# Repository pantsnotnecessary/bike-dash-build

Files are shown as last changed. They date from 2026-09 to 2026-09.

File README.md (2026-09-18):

# bike-dash-build

Hardware + software build notes for the **permanent** electric-motorcycle dash.
This repo is the "how to build it" companion to two existing repos:

| Repo | What it holds |
|---|---|
| [pantsnotnecessary/bike-dash](https://github.com/pantsnotnecessary/bike-dash) (private) | The dash firmware (ESPHome/LVGL): GPS speed, BMS status, media strip, SD ride log |
| [pantsnotnecessary/ant-bms-epaper-gauge](https://github.com/pantsnotnecessary/ant-bms-epaper-gauge) (public) | The original e-paper SOC gauge; the ANT-BMS BLE logic came from here |

## The decision (2026-09-18)

Cost is not a factor. Performance and start-up time are.

| Question | Answer |
|---|---|
| Compute | **ESP32-P4 + ESP32-C6** under ESPHome. About 3 s from key-on to a usable screen. Everything already written for bike-dash carries over. |
| Why not a Pi / Linux board | 15-30 s boot. Rejected. |
| Why not STM32H7 | Under 1 s boot but no BLE and nothing carries over. Rejected. |
| Why not the Waveshare ESP32-P4-7B we started on | Its panel is **350 nits, 0-60 C**. Every ESP32-P4 all-in-one board on the market (Waveshare, Guition, Elecrow) is an indoor panel. A bike dash in direct sun needs about 1000 nits. |
| Screen | **Riverdi RVT70HSMNWC00-B**: 7" 1024x600 IPS, **850 cd/m2**, optically bonded PCAP touch, anti-glare, **-20 to 70 C**, glove and wet-screen touch. Controller EK79007 (same family as Espressif's own dev panel), runs 2-lane. |
| Board | **Waveshare ESP32-P4-NANO** (P4 + onboard C6, 32 MB PSRAM, 16 MB flash, microSD, 22-pin 2-lane DSI). |
| Glue | Two FPC breakouts for the bench, a PT4115 constant-current driver for the 9.6 V / 270 mA backlight, a Pololu 5 V buck off the bike's 12 V. A small carrier PCB replaces the breakouts for the on-bike install. |

## Bench wiring at a glance

Bench wiring diagram

Full pin-by-pin steps, checks and troubleshooting: [docs/wiring.md](docs/wiring.md).

## Where things are

| File | Contents |
|---|---|
| [docs/bom.md](docs/bom.md) | Every part, price, link, and order status |
| [docs/wiring.md](docs/wiring.md) | **Pin-for-pin wiring guide.** Start here when the parts arrive. |
| [docs/hardware.md](docs/hardware.md) | Pinouts, panel electrical limits, timings, gotchas (the reference behind the wiring guide) |
| [docs/software.md](docs/software.md) | ESPHome bring-up plan, versions, stages |
| [esphome/bike-dash-p4nano.yaml](esphome/bike-dash-p4nano.yaml) | Starting config: P4-NANO + Riverdi panel as a `mipi_dsi` CUSTOM model |
| [docs/build-log.md](docs/build-log.md) | Dated log of what was done and what was learned |
| [enclosure/](enclosure/README.md) | OpenSCAD model, STLs and previews of the printed housing (bezel, retainer, shell, GPS cap) |

## Enclosure at a glance

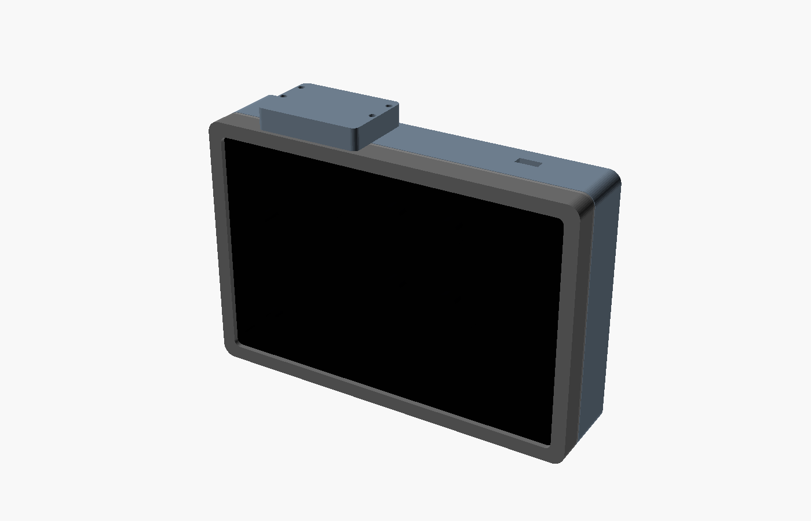
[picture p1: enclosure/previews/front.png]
Enclosure mockup


Four printed parts, PETG/ASA, M3 inserts. Details, hardware list and the VERIFY table: [enclosure/README.md](enclosure/README.md).

## Status

- 2026-09-18: research done, all core parts ordered (Amazon plus the Riverdi panel from DigiKey). Nothing built yet.
- 2026-09-18: enclosure mockup modelled in OpenSCAD, STLs exported. Several dimensions still need calipers on the real parts (see enclosure/README.md).

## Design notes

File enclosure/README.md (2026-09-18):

# Enclosure

Parametric OpenSCAD model of the dash housing: [bike-dash-enclosure.scad](bike-dash-enclosure.scad).
Four printed parts, all plastic so the BLE and GPS antennas work from inside.

Front

| View | Image |
|---|---|
| Exploded (bezel, retainer, shell, GPS cap) | [previews/exploded.png](previews/exploded.png) |
| Shell inside, boards as coloured blocks | [previews/shell-inside.png](previews/shell-inside.png) |
| Back, AMPS pattern and 7 assembly screws | [previews/back.png](previews/back.png) |
| Bezel from behind, insert holes and tail relief | [previews/bezel-back.png](previews/bezel-back.png) |
| GPS cap from inside | [previews/gpscap-inside.png](previews/gpscap-inside.png) |

## Parts

| Part | STL | Print orientation | What it does |
|---|---|---|---|
| Bezel | [stl/bezel.stl](stl/bezel.stl) | face down | Front frame. 4 mm lip over the glass edge on a foam gasket, glass pocket, then a TFT pocket open to the back. 7 x M3 heat-set inserts from the back. |
| Retainer | [stl/retainer.stl](stl/retainer.stl) | flat | 2 mm plate clamped between bezel and shell. Its raised frame enters the TFT pocket and presses the TFT back edge through 1 mm foam, so the panel cannot walk backwards under vibration. Slot in the bottom bar for the FPC tail. |
| Shell | [stl/shell.stl](stl/shell.stl) | back down | Rear box, 24 mm cavity. Standoffs for the P4-NANO (M2.5 self-tap) and Pololu, adhesive pads for the two FPC breakouts and the PT4115, PG7 gland in the bottom wall, USB-C slot in the top wall for bench flashing, AMPS 30 x 38 bosses with M4 inserts on the back, thick pad under the top wall for the GPS cap screws. |
| GPS cap | [stl/gpscap.stl](stl/gpscap.stl) | open side up | Cup on the top edge. The SparkFun NEO-M9N lies flat against the 1.5 mm roof, chip antenna to the sky. 4 x M3 button heads through the roof into inserts in the shell. |

Overall size 185.6 x 124.6 x 41.7 mm, GPS cap adds 10.6 mm on the top edge.

## Hardware to fit it together

| Item | Qty | Where |
|---|---|---|
| M3 heat-set insert, 4.0 mm OD x 5.7 mm | 11 | 7 in the bezel, 4 in the shell top wall (GPS cap) |
| M3 x 35 socket cap screw | 7 | shell back, through the bosses, into the bezel |
| M3 x 16 button head | 4 | GPS cap roof into the shell |
| M3 x 6 self-tapping (or M3 x 6 into 2.5 mm pilot) | 4 | GPS board to the cap standoffs |
| M2.5 x 8 self-tapping | 4 | P4-NANO to its standoffs |
| M2 x 6 self-tapping | 2 | Pololu buck |
| M4 heat-set insert, 5.6 mm OD x 8 mm | 4 | AMPS bosses on the back |
| PG7 cable gland | 1 | bottom wall, 12 V feed |
| Foam tape 1 mm, 5 mm wide | 1 m | gasket under the bezel lip; strip on the retainer frame |
| Double-sided foam tape | some | PT4115 and both FPC breakouts on their pads |

## Print settings

PETG or ASA (the dash sits in the sun; PLA will sag). 0.2 mm layers, 4 walls, 30 % infill, no supports needed in the orientations above. The bezel face is the visible surface, so use a textured or smooth PEI sheet. Print the retainer first: it is a 2 minute test of the screw pattern against the bezel.

## Regenerate

```
cd enclosure
for p in bezel retainer shell gpscap; do openscad -o stl/$p.stl -D "part=\"$p\"" bike-dash-enclosure.scad; done
openscad -o previews/front.png --imgsize=1400,900 --viewall --autocenter --projection=p --colorscheme=Tomorrow --camera=300,-500,300,0,0,0 -D 'part="assembly"' bike-dash-enclosure.scad
```

Other `part` values: `exploded`, `shell_inside`, `gpscap_inside`, `placeholders`.

## VERIFY before the final print

Every number tagged `VERIFY` in the .scad came from a drawing or listing, not from the part in hand.

| Dimension | Value used | Source | Check |
|---|---|---|---|
| Glass outline and thickness | 179.96 x 119.0 x 1.1 mm | Riverdi listing for the -B touch part | Calipers on the panel; the -B datasheet was not downloadable (404 on every revision tried) |
| TFT offset inside the glass | centred | assumption | The tail side is usually wider. Measure and set `tft_off` |
| Tail width and position | 30 mm, centred on the bottom edge | assumption | Measure; set `tail_w`, `tail_x`. The retainer slot and bezel relief follow |
| P4-NANO mounting holes | 45.10 x 45.09 mm, 2.7 mm | Waveshare dimension drawing | Hole diameter is a guess from the "R2.00" callout |
| RJ45 jack height | 13.5 mm | typical | Sets the 24 mm cavity depth |
| SparkFun M9N | 40.64 x 33.02 mm, holes 35.56 x 27.94, 3.3 mm | SparkFun board drawing | Component height (4.5 mm) is a guess |
| Pololu D36V28F5 holes | 2 holes 15.24 mm apart | Pololu | Confirm spacing and hole size |
| PT4115 module | 30 x 20 mm | guess | Measure on arrival. Adhesive pad, so only the pad size changes |
| MECCANIXITY breakouts | 22P 29 x 26, 40P 54 x 26 | Amazon listing | Adhesive pads; if they have holes, add standoffs |
| Glass-to-bezel fit | 0.3 mm per side | print tolerance | Print the bezel first and trial-fit before printing the shell |

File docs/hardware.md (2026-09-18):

# Hardware reference

This is the reference behind [wiring.md](wiring.md). Read wiring.md to build it; come here when something does not work.

## Riverdi RVT70HSMNWC00-B panel

Datasheet (no-touch sibling, same glass and electronics): [DS_RVT70HSMNWN00 Rev 1.4](https://download.riverdi.com/RVT70HSMNWN00/DS_RVT70HSMNWN00_Rev.1.4.pdf). Do not commit the PDF, link it.

| Item | Value |
|---|---|
| Controller | EK79007AD3 + EK73217BCGA (datasheet drawing). Espressif ships `esp_lcd_ek79007`; ESPHome `mipi_dsi` drives it as `model: CUSTOM` |
| Resolution | 1024 x 600, IPS, normally black, anti-glare |
| Brightness | 1000 cd/m2 bare; 850 cd/m2 with the optically bonded touch |
| Operating temp | -20 to 70 C (storage -30 to 80) |
| Logic supply | VDD 3.3 V (2.6-3.6), about 168 mA |
| Backlight | 27 white LEDs, **Vf 9.6 V (9.0-10.2), If 270 mA typ, 315 mA max**, about 2.6 W. No driver on the panel. |
| Touch | ILITEK ILI2132A PCAP, I2C, 10-point, thick-glove and wet operation, up to 8 mm cover glass. Not supported by ESPHome yet. |
| Size | 164.9 x 100 x 5.7 mm outline, 154.21 x 85.92 mm active |
| Tail | 40-pin 0.5 mm pitch FPC, 0.3 mm thick, contacts on one side |

### 40-pin FPC pinout (datasheet)

| Pin | Name | Note |
|---|---|---|
| 1 | NC | |
| 2, 3 | VDD | 3.3 V |
| 4 | NC | |
| 5 | RESET | active low; datasheet Note 1 has a recommended RC reset circuit |
| 6 | STBYB | standby, tie to 3.3 V for normal operation |
| 7 | GND | |
| 8, 9 | D0N, D0P | MIPI lane 0 |
| 10 | GND | |
| 11, 12 | D1N, D1P | MIPI lane 1 |
| 13 | GND | |
| 14, 15 | D2N, D2P | lane 2, **leave unconnected** (P4 is 2-lane) |
| 16 | GND | |
| 17, 18 | DCLKN, DCLKP | MIPI clock |
| 19 | GND | |
| 20, 21 | D3N, D3P | lane 3, **leave unconnected** |
| 22-30 | GND / NC / U-D, L-R scan direction | see the datasheet pin table; U/D and L/R set scan direction (GND/VDD combos). Leave the NC pins alone. |
| 31, 32 | LED- | backlight cathode |
| 33-38 | NC | |
| 39, 40 | LED+ | backlight anode |

### Init sequence (datasheet p.16). This is what goes in the ESPHome `init_sequence`

```
0x01            ; DCS software reset
delay 120 ms
0xB2 0x50       ; lanes: 0x50 = 2-lane, 0x60 = 3, 0x70 = 4   <-- P4 uses 2
0x80 0x4B       ; gamma
0x81 0xFF
0x82 0x1A
0x83 0x88
0x84 0x8F
0x85 0x35
0x86 0xB0
0x11            ; exit sleep
delay 120 ms
0x29            ; display on
delay 20 ms
```

### Timing (datasheet, typical / range)

| Parameter | Typ | Range |
|---|---|---|
| Pixel clock | 51.2 MHz | 44.9-63 MHz |
| H active | 1024 | |
| HSYNC pulse | 70 | 1-140 |
| H back porch | 160 | fixed |
| H front porch | 160 | 16-216 |
| V active | 600 | |
| VSYNC pulse | 10 | 1-20 |
| V back porch | 23 | fixed |
| V front porch | 12 | 1-127 |

### Gotchas from the datasheet

- **THS_ZERO**: the panel's MIPI receiver does not meet the MIPI minimum. If the host's THS_ZERO sits at the low end the panel silently fails to init. If the screen stays black with a good init log, this is the first thing to look at (ESP-IDF DSI PHY timing).
- The Waveshare 7B ESPHome preset for the same panel class uses `lane_bit_rate: 900Mbps`, `pclk 52MHz`, hsync 10/160/160, vsync 1/23/12. Good starting point.

## Waveshare ESP32-P4-NANO

Wiki: https://www.waveshare.com/wiki/ESP32-P4-Nano-StartPage . Schematic: https://files.waveshare.com/wiki/ESP32-P4-NANO/ESP32-P4-NANO-schematic.pdf

| Item | Value |
|---|---|
| SoC | ESP32-P4NRW32, 32 MB PSRAM in package, 16 MB QSPI flash |
| Radio | ESP32-C6-MINI-1 over SDIO: reset GPIO54, cmd 19, clk 18, d0-d3 = 14-17, active high (ESPHome device page) |
| I2C | SDA GPIO7, SCL GPIO8 (also on the DSI connector) |
| LCD reset (BSP default) | GPIO27 on the GPIO header |
| LCD backlight PWM (BSP default) | GPIO26 on the GPIO header |
| DSI | 22-pin 0.5 mm FPC, 2 lanes + clock. The schematic also routes GPIO37, GPIO38, SDA/SCL and 3.3 V to it. We only use the six MIPI signals and ground from this connector; reset and backlight go from the header instead. |
| Power | USB-C, or 5 V on the header, or PoE module |
| Storage | microSD, SDIO 3.0 |
| ESPHome presets that exist for this board | `WAVESHARE-P4-NANO-10.1` (their 10.1" DSI panel); copy only the board-level bits |

## PT4115 backlight driver module

- Buck topology: Vin must be above the LED string (9.6 V) plus about 1 V. 12 V is fine. 5 V is not.
- Output current is fixed by the module's sense resistor: **I = 0.1 V / Rs**. Target 270 mA, so Rs about 0.37 ohm. 0.33 ohm gives about 300 mA (under the 315 mA max), 0.39 ohm gives about 256 mA. **Read the resistor on the module before connecting the panel** (see wiring.md step 3). Three modules were bought so one can be modified.
- DIM pin: PWM 100 Hz-20 kHz from a P4 GPIO, 3.3 V logic is enough. Left floating = full on. Use about 5 kHz so it is not visible.

## Pololu D36V28F5

5.3-50 V in, 5 V 3.2 A out, reverse-polarity protected, has an EN pin (tie to ignition-switched 12 V if we want the dash off with the key without a relay).

## On-bike carrier PCB (later)

Replace both breakouts and the jumpers with one board: 22-pin FPC in, 40-pin FPC out, DSI pairs as 100 ohm differential traces, PT4115 + Pololu footprints (or discrete equivalents), fuse, ignition-sense input. Design it only after the bench build shows the panel initialising.

## Antennas

None to buy for the bench. All radios have on-board antennas; the rules for the bike install:

| Radio | Rule |
|---|---|
| BLE, C6 on the P4-NANO (PCB antenna) | Plastic enclosure. Keep the NANO away from the panel's driver strip and the MIPI wires; the e-paper gauge showed display electronics desensing the radio. |
| GPS, SparkFun chip antenna | Must see sky: top of the enclosure, plastic lid, nothing metal above it. If first fix is slow or speed drops out, swap to the SparkFun NEO-M9N u.FL version plus a small active patch antenna (about $12) mounted outside. |
| XIAO C6 (contingency) | Same as BLE; it has a u.FL socket if an external antenna is ever needed. |
| Metal enclosure | Do not. Everything would need external antennas. |

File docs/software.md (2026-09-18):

# Software plan

The dash application lives in [bike-dash](https://github.com/pantsnotnecessary/bike-dash). This repo only covers getting the new hardware to light up. Once the display works, the bike-dash YAML gets its `esp32`, `esp32_hosted`, `display` and `light` blocks swapped for the ones here.

## Versions

| Thing | Requirement |
|---|---|
| ESPHome | 2026.9 or newer. 2026.8 fixed the ESP32-P4 rev3 bootloop; 2026.9 dropped the old `esp_hosted` 2.0.11 path that double-freed on P4+C6 |
| Framework | esp-idf only (no Arduino on P4), IDF 5.3 or newer for `esp32_hosted` |
| Build host | Linux is easiest (the gaming PC on CachyOS). Windows works from PowerShell, **not** MSys/Git-Bash (idf_tools.py rejects it) |

## Bring-up stages

| Stage | Goal | Done when |
|---|---|---|
| 0 | P4-NANO boots ESPHome, C6 comes up | logs show Wi-Fi/BLE from `esp32_hosted`. **Do this with nothing but USB plugged in.** |
| 1 | Riverdi panel initialises | backlight on, screen not black, no DSI errors in the log. The test lambda fills the screen green with a grey box |
| 2 | LVGL hello at 1024x600 | a label renders, no tearing, PSRAM frame buffer |
| 3 | Merge bike-dash UI | the speed-hero layout from bike-dash renders here |
| 4 | BMS BLE over the C6 | `'soc': Sending state NN %` in the log (same GO/NO-GO as bike-dash Stage 1) |
| 5 | GPS, SD logging, phone media | iPhone only. Apple Media Service (AMS) over BLE: **play/pause, volume up/down** are the required controls; next/previous and track title come free with it. Custom ESPHome component (esp-idf). Fallback if AMS fights us: a BLE HID consumer-control device (media keys), which iOS also accepts natively but gives no track info. No Android support needed. |
| 6 | Touch (optional) | ILI2132A is **not** an ESPHome touchscreen platform and would need a custom component. The dash does not need touch to be useful, so this is last |

## The display block

See [esphome/bike-dash-p4nano.yaml](../esphome/bike-dash-p4nano.yaml). Key points:

- `model: CUSTOM` with `dimensions`, timings and the datasheet `init_sequence` (see hardware.md).
- `lanes: 2` and the `0xB2 0x50` byte in the init sequence must agree.
- Start at `lane_bit_rate: 900Mbps` and `pclk_frequency: 51.2MHz`; if the picture is scrambled try 800-1000 Mbps.
- If it stays black with a clean log: THS_ZERO (hardware.md), then RESET polarity and timing, then STBYB.

## Commands

```
esphome config esphome/bike-dash-p4nano.yaml                          # validate
esphome run    esphome/bike-dash-p4nano.yaml --device /dev/ttyACM0    # Linux
esphome run    esphome/bike-dash-p4nano.yaml --device COM4            # Windows PowerShell
```

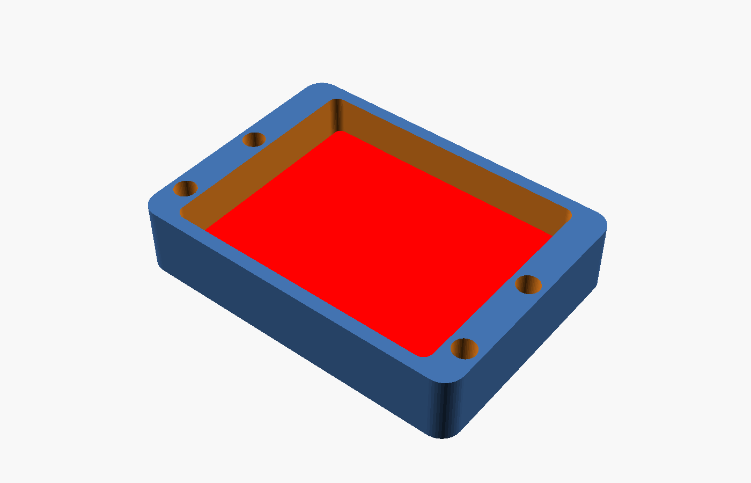
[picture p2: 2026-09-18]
enclosure/previews/gpscap-inside.png

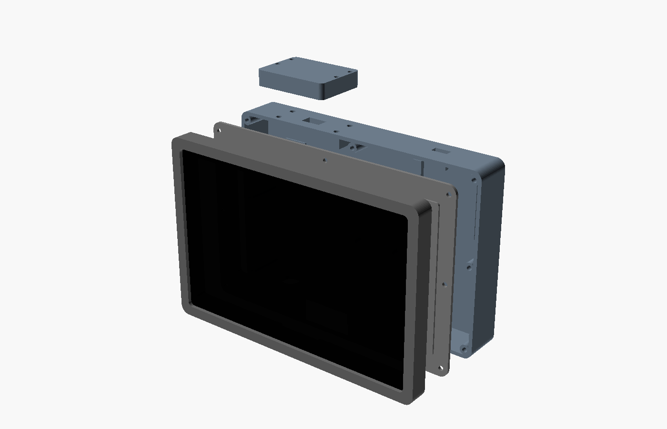
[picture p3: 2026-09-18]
enclosure/previews/exploded.png

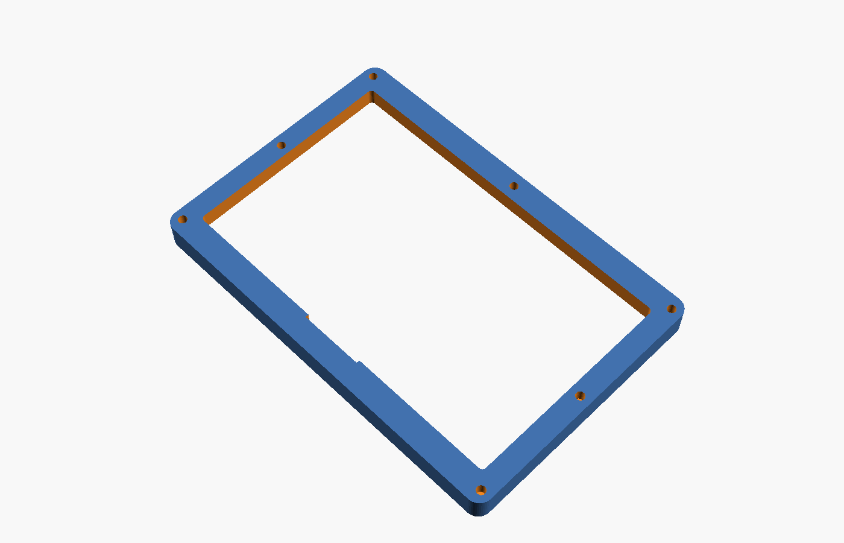
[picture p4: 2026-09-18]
enclosure/previews/bezel-back.png

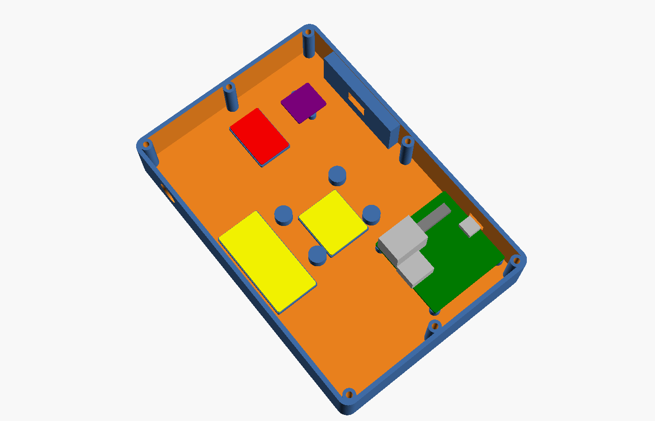
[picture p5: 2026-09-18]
enclosure/previews/shell-inside.png

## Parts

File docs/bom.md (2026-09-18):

# Bill of materials

Ordered 2026-09-18 unless noted. Prices are what was on screen that day.

## Core

| # | Part | Vendor | Price | Link | Status |
|---|---|---|---|---|---|
| 1 | Riverdi RVT70HSMNWC00-B, 7" 1024x600 IPS 850 cd/m2 optical-bonded PCAP touch, MIPI-DSI, no frame | DigiKey (SM-RVT70HSMNWC00-B V1.0A) | $116.07 | [DigiKey](https://www.digikey.com/en/products/detail/riverdi/SM-RVT70HSMNWC00-B-V1-0A/25855280) / [Riverdi direct $113.52](https://riverdi.com/product/high-brightness-ips-display-rvt70hsmnwc00-b-7-inch-projected-capacitive-touch-panel-optical-bonding-uxtouch-mipi-dsi) | ordered 2026-09-18 |
| 2 | Waveshare ESP32-P4-NANO (bare board) | Amazon | $28.79 | [search, first result](https://www.amazon.com/s?k=Waveshare+ESP32-P4-NANO) | ordered 2026-09-18 |
| 3 | MECCANIXITY 40-pin 0.5 mm FPC breakout, 2-pack (panel side) | Amazon | $7.99 | [B09VPHW2QY](https://www.amazon.com/MECCANIXITY-Converter-Socket-2-54mm-Printer/dp/B09VPHW2QY) | ordered 2026-09-18 |
| 4 | MECCANIXITY 22-pin 0.5 mm FPC breakout, 2-pack (P4-NANO DSI side) | Amazon | $9.39 | [B09VPKWL1G](https://www.amazon.com/MECCANIXITY-Converter-2-54mm-Single-Printer/dp/B09VPKWL1G) | ordered 2026-09-18 |
| 5 | PT4115 constant-current LED driver module, 3-pack (backlight) | Amazon | $7.99 | [B0FR1SGWKM](https://www.amazon.com/PT4115-Constant-Current-Dimming-Step-Down/dp/B0FR1SGWKM) | ordered 2026-09-18 |
| 6 | Pololu D36V28F5 5 V 3.2 A buck, 5.3-50 V in (bike 12 V to 5 V) | Amazon | $16.99 | [B0BJKVWR2D](https://www.amazon.com/Pololu-3-2A-Step-Down-Voltage-Regulator/dp/B0BJKVWR2D) | ordered 2026-09-18 |
| 7 | **SparkFun GPS Breakout NEO-M9N, chip antenna (Qwiic)**: genuine u-blox M9, 25 Hz max, UART pins + I2C, **3.3 V supply and logic**, rechargeable backup battery keeps settings and gives a hot fix | Amazon | $74.95 | [B082YG1PXF](https://www.amazon.com/SparkFun-Breakout-Breadboardable-time-First-f/dp/B082YG1PXF) (Prime) | ordered 2026-09-18 |
| 8 | USB-to-TTL serial adapter, 3.3 V (for the one-time 10 Hz / 115200 setup in u-center) | Amazon | about $8 | any CP2102 or FT232 board with a 3.3 V switch | ordered 2026-09-18 |

All eight core parts ordered 2026-09-18 (Amazon plus the panel from DigiKey).

GPS notes: it is the speed source for the dash (speed and trip come from GPS, not the bike). Many cheap "NEO-M8N" boards on Amazon are clones with old firmware, so the SparkFun board is the pick. Alternative if it is out of stock: [Matek M9N-5883](https://www.amazon.com/s?k=Matek+M9N-5883) ($62.99, genuine, but **5 V supply**, JST-GH pigtail, and no flash: it forgets its settings when its supercap drains, so the `on_boot` block in the YAML becomes mandatory). Whatever module: it must run at **10 Hz** and **115200 baud** (factory default is 1 Hz at 9600 or 38400, too slow for a speedo). See wiring.md Step 4b.

## Still to source (bench)

| Part | Why | Notes |
|---|---|---|
| 22-pin 0.5 mm FFC cable, about 100 mm | P4-NANO DSI connector to the 22-pin breakout | Check contact side (same-side vs opposite) against the NANO connector and breakout. The NANO may ship with one; check the box. |
| Dupont jumper wires, female-female, 100 mm, one pack | Breakout to breakout, breakout to NANO header | Keep the six DSI wires **the same length and bundled together** |
| Screw terminal or small perfboard | To join grounds and 12 V feeds neatly | |
| 12 V bench supply, 2 A | Backlight + buck | A 12 V wall adapter with a barrel jack pigtail is fine |
| Multimeter | Checking the PT4115 sense resistor and the 5 V rail before connecting the panel | |

## Still to source (on-bike)

| Part | Why |
|---|---|
| Carrier PCB (22-pin DSI in, 40-pin panel out, PT4115, buck, connectors) | Replaces the two breakouts and jumper wires. Design after bench bring-up. |
| Enclosure + bezel for the 164.9 x 100 x 5.7 mm panel | Weatherproof, vibration |
| Automotive fuse (2 A) + inline connector on the 12 V feed | |

## Contingency (buy only if Stage 4 fails)

| Part | Why | Notes |
|---|---|---|
| Seeed XIAO ESP32-C6 (about $10, Amazon/Seeed) | Second BLE radio if the onboard C6 cannot hold the BMS link and the iPhone AMS link at once | Runs its own ESPHome firmware as the AMS peripheral; talks to the P4 over a spare UART (3V3, GND, TX, RX on two free header GPIOs). Onboard C6 keeps the BMS. Has a u.FL socket for an external antenna if the enclosure blocks BLE. |

## Alternatives that were rejected (so we do not re-research)

| Part | Why not |
|---|---|
| Waveshare ESP32-P4-WIFI6-Touch-LCD-7B ($47-56) | 350 nits. Fine as a bench unit, not the bike screen. Same ESPHome code otherwise. |
| Elecrow CrowPanel Advance 7" P4 (400 nits), Waveshare 7/8/10.1 HMI (400-450), Guition JC1060P470 | All indoor-brightness, 0-60 C panels |
| Riverdi STM32H7 7" 850-nit ($266) | No BLE, TouchGFX rewrite |
| Riverdi "ESP-P4 series" 10.1" 800-1000 nit all-in-one (coming soon) | Right idea, wrong size, no price or date. Watch it. |
| Amazon "1000 nit 7 inch" kits (VSDISPLAY etc.) | HDMI controller boards. The P4 has no HDMI out. |
| Adafruit 4905 40-pin breakout | Out of stock on Amazon; MECCANIXITY substituted |

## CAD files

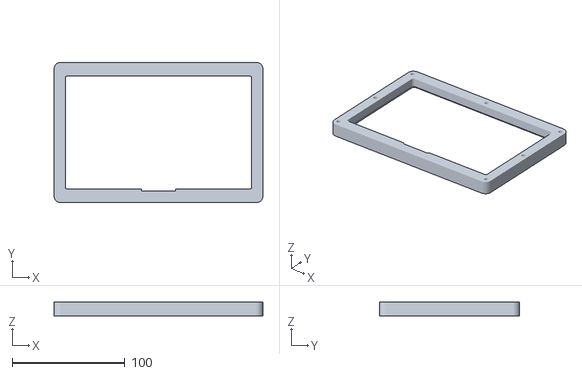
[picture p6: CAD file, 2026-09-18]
enclosure/stl/bezel.stl
185.6 x 124.6 x 12.7

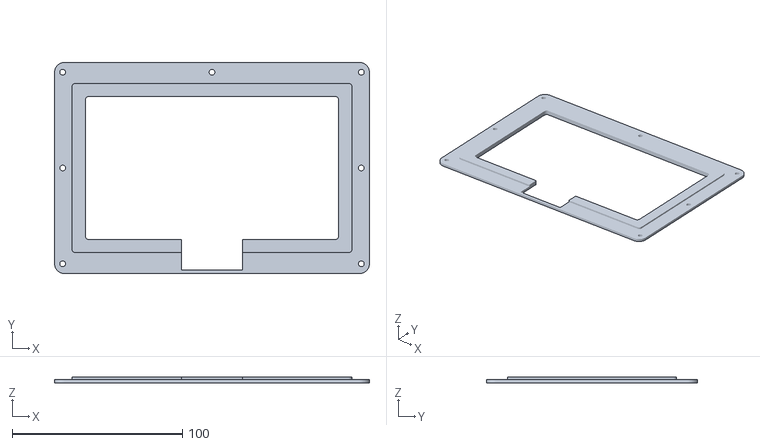
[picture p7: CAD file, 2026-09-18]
enclosure/stl/retainer.stl
185.2 x 124.2 x 3.30

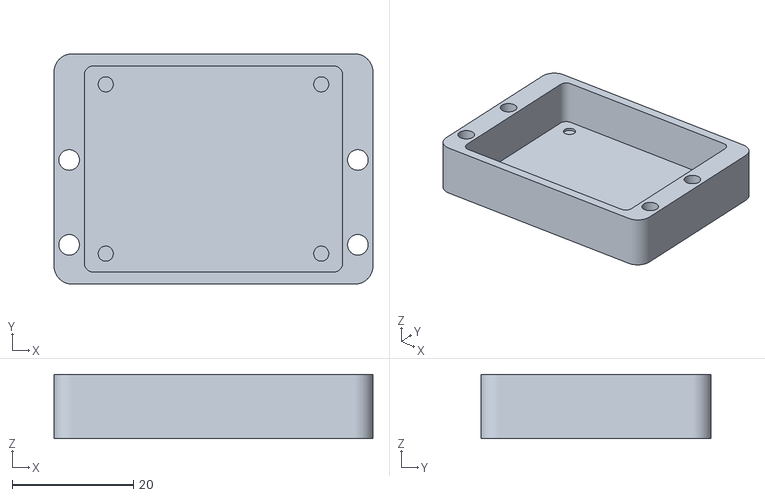
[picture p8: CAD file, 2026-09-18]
enclosure/stl/gpscap.stl
52.6 x 38.0 x 10.6

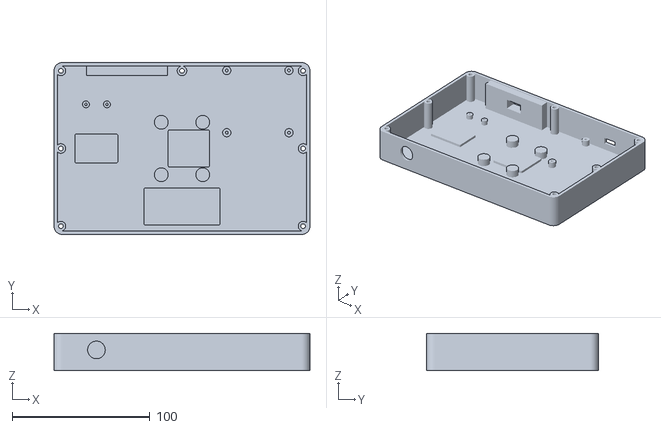
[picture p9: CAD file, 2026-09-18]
enclosure/stl/shell.stl
185.6 x 124.6 x 27.0

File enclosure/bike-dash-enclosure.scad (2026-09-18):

// bike-dash enclosure  -  parametric OpenSCAD model (OpenSCAD 2021.01+)
// ---------------------------------------------------------------------------
// Four printed parts, all plastic (BLE + GPS antennas live inside):
//   bezel     front frame; clamps the Riverdi glass; M3 heat-set inserts
//   retainer  2 mm plate sandwiched between bezel and shell; presses the TFT
//             back edge (with 1 mm foam) so the panel cannot walk backwards
//   shell     rear box; standoffs for P4-NANO, pads for breakouts / PT4115 /
//             Pololu; PG7 gland for the 12 V feed; AMPS 30 x 38 mount bosses
//   gpscap    cup on the TOP edge; SparkFun NEO-M9N lies flat, chip antenna
//             toward the sky under a 1.5 mm roof
//
// Render one part:   openscad -D 'part="bezel"' -o bezel.stl bike-dash-enclosure.scad
// Parts: bezel | retainer | shell | gpscap | assembly | exploded | placeholders
//
// Every number tagged VERIFY was taken from a drawing, a listing or is an
// assumption; measure the real part before printing the final version.
// Coordinates: X = left/right, Y = up (toward the sky), Z = front (rider) / back.
// Each part is modelled in its print orientation with the bed at z = 0.
// ---------------------------------------------------------------------------

part = "assembly";
$fn = 48;

// ---------- Riverdi RVT70HSMNWC00-B (touch, optically bonded) --------------
glass_w = 179.96;   // VERIFY  -B cover-glass outline (Riverdi listing)
glass_h = 119.0;    // VERIFY
glass_t = 1.1;      // VERIFY  cover glass thickness
tft_w   = 164.9;    // datasheet DS_RVT70HSMNWN00 Rev1.4 (same TFT)
tft_h   = 100.0;
tft_t   = 5.7;
act_w   = 154.21;   // active area
act_h   = 85.92;
tft_off = [0, 0];   // VERIFY  TFT centre offset inside the glass (tail side likely wider)
tail_w  = 30;       // VERIFY  FPC tail width; exits the TFT on the BOTTOM long edge
tail_x  = 0;        // VERIFY  tail centre x
tail_edge_relief = 1.5;  // notch in the TFT pocket wall for a tail that leaves at the edge

// ---------- Waveshare ESP32-P4-NANO ----------------------------------------
nano_w = 50.0;  nano_h = 50.0;  nano_t = 1.6;     // wiki dimension drawing
nano_hole_dx = 45.10;  nano_hole_dy = 45.09;      // wiki drawing (2.45 from edges)
nano_hole_d  = 2.7;    // VERIFY  drawing says R2.00 at the corner; M2.5 assumed
nano_tall    = 13.5;   // VERIFY  RJ45 jack height, tallest part on the board
nano_pos     = [55, 34];  // centre in the shell cavity (USB-C nose at the top wall)
nano_usb_x   = 0;      // USB-C sits on the board centre line (drawing: 20.52 each side)

// ---------- SparkFun GPS NEO-M9N chip antenna (GPS-15733) ------------------
gps_w = 40.64;  gps_h = 33.02;  gps_t = 1.6;      // 1.60 x 1.30 in board drawing
gps_hole_dx = 35.56;  gps_hole_dy = 27.94;        // 1.40 x 1.10 in
gps_hole_d  = 3.3;                                // 0.13 in
gps_comp_h  = 4.5;     // VERIFY  tallest component (backup battery / u-blox can)
gps_cap_x   = -40;     // cap centre along the top wall

// ---------- Small boards --------------------------------------------------
pololu_w = 17.8;  pololu_h = 20.3;  pololu_hole_dx = 15.24;  // D36V28F5; VERIFY holes
pt4115_w = 30;    pt4115_h = 20;                              // VERIFY  measure on arrival
bo22_w   = 29;    bo22_h   = 26;                              // MECCANIXITY 22P, VERIFY
bo40_w   = 54;    bo40_h   = 26;                              // MECCANIXITY 40P, VERIFY
pad_t    = 2;     // adhesive-pad standoff height for the boards without known holes

pololu_pos = [-62, 32];
pt4115_pos = [-62,  0];
bo22_pos   = [  5,  0];   // between the AMPS bosses, 22P FFC (100 mm) reaches the NANO
bo40_pos   = [  0, -42];   // right where the panel tail arrives (bottom edge)

// ---------- Enclosure ------------------------------------------------------
wall     = 2.5;    // side walls
back_t   = 3.0;    // shell back wall
face_t   = 2.5;    // bezel front lip
lip      = 4.0;    // how far the bezel lip overlaps the glass edge
clr      = 0.3;    // per-side fit clearance
gasket   = 0.5;    // foam gasket under the lip (compressed)
foam     = 1.0;    // foam between retainer and TFT back
corner_r = 6;
cav_d    = 24;     // shell cavity depth (RJ45 13.5 + 5 standoff + 1.6 board + wiring)
ret_t    = 2.0;    // retainer plate
ret_frame_w = 8;   // width of the pressure frame on the retainer
ret_lip  = 1.3;    // raised frame on the retainer that enters the TFT pocket

ins_m3_d = 4.0;  ins_m3_h = 6.0;   // M3 heat-set insert (4.0 x 5.7 typical)
ins_m4_d = 5.6;  ins_m4_h = 8.0;   // M4 heat-set insert
m3_clr   = 3.4;  m3_cb_d = 6.5;  m3_cb_h = 3.0;

gland_d  = 12.8;   // PG7 cable gland thread hole
gland_x  = -62;
usb_port = true;   // cutout in the top wall for the NANO USB-C (bench flashing)

amps_dx = 30;  amps_dy = 38;  amps_boss_d = 10;  amps_boss_h = 9;   // AMPS 4-hole, M4

// ---------- Derived --------------------------------------------------------
gp_d   = glass_t + gasket + clr;          // glass pocket depth
tp_d   = tft_t + foam + clr + ret_lip;    // TFT pocket depth (retainer lip enters it)
bez_d  = face_t + gp_d + tp_d;            // bezel total depth
out_w  = glass_w + 2*(clr + wall);
out_h  = glass_h + 2*(clr + wall);
shell_d = back_t + cav_d;
cav_w  = out_w - 2*wall;
cav_h  = out_h - 2*wall;
total_d = bez_d + ret_t + shell_d;

// screw positions: 4 corners + 2 mid sides + 1 top mid (bottom mid skipped: tail)
band_x = ((tft_w/2 + clr) + out_w/2) / 2;
band_y = ((tft_h/2 + clr) + out_h/2) / 2;
screws = [[ band_x,  band_y], [-band_x,  band_y], [ band_x, -band_y], [-band_x, -band_y],
          [ band_x, 0], [-band_x, 0], [0, band_y]];

gps_side_w = 5;                           // thick side walls carry the cap screws
gps_cap_w  = gps_w + 2*(1 + gps_side_w);
gps_cap_l  = gps_h + 2*(0.5 + 2);        // along Z; must stay behind the bezel face
gps_cap_h  = 2 + gps_t + gps_comp_h + 1 + 1.5;   // standoff + board + parts + air + roof
gps_pad_t  = 7;                           // thick pad under the top wall for the inserts
gps_sx     = gps_w/2 + 1 + gps_side_w/2;  // screw centre line inside the side wall
gps_screw  = [[ gps_sx, 8], [-gps_sx, 8], [ gps_sx, 22], [-gps_sx, 22]];   // [x, z-from-shell-back]
gps_cap_z0 = 1.5;                         // cap starts 1.5 mm in from the shell back face

echo(str("outer ", out_w, " x ", out_h, " mm, depth ", total_d, " mm (+ GPS cap ", gps_cap_h, ")"));

// ---------- Helpers --------------------------------------------------------
module rrect(w, h, r) { offset(r = r) offset(delta = -r) square([w, h], center = true); }
module rbox(w, h, d, r) { linear_extrude(height = d) rrect(w, h, r); }
module at(p) { translate([p[0], p[1], 0]) children(); }
module hole(d, h, z = 0) { translate([0, 0, z]) cylinder(d = d, h = h); }

// ===========================================================================
// BEZEL  (printed face-down: front face on the bed at z = 0)
// ===========================================================================
module bezel() {
    difference() {
        rbox(out_w, out_h, bez_d, corner_r);
        // window
        translate([0, 0, -1]) rbox(glass_w - 2*lip, glass_h - 2*lip, face_t + 2, 3);
        // glass pocket
        translate([0, 0, face_t]) rbox(glass_w + 2*clr, glass_h + 2*clr, gp_d + 0.01, 1.5);
        // TFT pocket, open to the back
        translate([tft_off[0], tft_off[1], face_t + gp_d])
            rbox(tft_w + 2*clr, tft_h + 2*clr, tp_d + 1, 2);
        // tail relief on the bottom pocket wall
        translate([tail_x + tft_off[0], -(tft_h/2 + clr) - tail_edge_relief/2 + tft_off[1], face_t + gp_d])
            linear_extrude(tp_d + 1) square([tail_w, tail_edge_relief + 0.02], center = true);
        // heat-set inserts from the back
        for (s = screws) at(s) hole(ins_m3_d, ins_m3_h + 0.01, bez_d - ins_m3_h);
    }
}

// ===========================================================================
// RETAINER  (flat plate, printed as is)
// ===========================================================================
module retainer() {
    win_w = tft_w - 2*ret_frame_w;
    win_h = tft_h - 2*ret_frame_w;
    difference() {
        union() {
            rbox(out_w - 0.4, out_h - 0.4, ret_t, corner_r);
            // raised pressure frame entering the TFT pocket
            translate([tft_off[0], tft_off[1], ret_t])
                rbox(tft_w + 2*clr - 1, tft_h + 2*clr - 1, ret_lip, 2);
        }
        translate([tft_off[0], tft_off[1], -1]) rbox(win_w, win_h, 10, 2);
        // tail slot through the bottom bar
        translate([tail_x + tft_off[0], -(tft_h/2) + tft_off[1], -1])
            linear_extrude(10) square([tail_w + 6, 2*ret_frame_w + 4], center = true);
        for (s = screws) at(s) hole(m3_clr, 10, -1);
    }
}
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

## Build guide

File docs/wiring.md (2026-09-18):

# Wiring guide (bench build)

Written for someone who is not a wiring person. Every connection is listed pin by pin. Do the steps in order and do not skip the checks; the panel is the expensive part and the backlight is the one thing that can cook it.

## What you are building

Bench wiring diagram: every wire, colour-coded, with pin numbers at both ends

Same thing as text, for when the picture is too small on a phone:

```
                 +---------------------+          +--------------------------+
 12 V supply --->| Pololu D36V28F5     |--5 V---->| Waveshare ESP32-P4-NANO  |
    (bench:      | (12 V in, 5 V out)  |          |   22-pin DSI connector   |----22-pin FFC----> [22P breakout]
     wall wart;  +---------------------+          |   GPIO header            |                          |
     bike: fused                                  +--------------------------+                    6 short jumpers
     ignition 12 V)                                    |  GPIO27 (reset)  GPIO26 (dim)  3V3  GND        |
         |                                             |     |               |          |    |           v
         |       +---------------------+               |     |               |          |    |     [40P breakout] <--panel tail-- Riverdi 7" panel
         +------>| PT4115 LED driver   |---LED+ / LED- ------------------------------------------------> pins 39/40 and 31/32
                 | (12 V in, 270 mA CC)|<-- DIM from GPIO26
                 +---------------------+
```

Three groups of wires:
1. **Power**: 12 V to the Pololu and the PT4115; 5 V from the Pololu to the P4-NANO; 3.3 V from the P4-NANO to the panel; one shared ground.
2. **Control**: panel RESET from GPIO27, PT4115 DIM from GPIO26, panel STBYB tied to 3.3 V.
3. **Video**: six MIPI wires (three pairs) from the P4-NANO's DSI connector to the panel. These are the only fussy ones.

## Tools

Multimeter, small flat screwdriver for the terminal blocks, wire strippers, a pack of female-female Dupont jumpers (100 mm), tweezers for the FPC latches, a 12 V 2 A supply.

## Step 0. Board alone, no panel (Stage 0 in software.md)

1. Plug the P4-NANO into the PC over USB-C. Nothing else connected.
2. Flash `esphome/bike-dash-p4nano.yaml` with the `display:` block commented out.
3. Confirm the log shows the C6 radio coming up and Wi-Fi connecting. If this does not work, nothing else matters yet.

## Step 1. Check the PT4115 module before it ever touches the panel

The module sets its current with a resistor marked something like `R100`, `R150`, `R200`, `R330`, `R390`. Find it (a small black rectangle next to the big chip). Current = 0.1 V / resistance:

| Marking | Ohms | Current | OK for this panel? |
|---|---|---|---|
| R330 | 0.33 | 300 mA | Yes (max is 315) |
| R390 | 0.39 | 256 mA | Yes (a touch dim, fine) |
| R100 | 0.10 | 1000 mA | **NO. Will destroy the backlight.** |
| R150 / R200 | 0.15 / 0.20 | 670 / 500 mA | **NO** |

If all three modules are above 315 mA, do not use them. Buy a module marked R330/R390, or replace the resistor. Do not guess.

Then test the driver on its own: connect 12 V to Vin+/Vin-, put the multimeter on the **LED output in current mode (mA)** between LED+ and LED-. It should read roughly the number in the table. Disconnect.

## Step 2. Power wiring

All terminal blocks: strip 6 mm, insert, tighten, tug-test.

| From | To | Wire |
|---|---|---|
| 12 V supply + | Pololu **VIN** | red |
| 12 V supply - | Pololu **GND** | black |
| 12 V supply + | PT4115 **VIN+** (or "IN+") | red |
| 12 V supply - | PT4115 **VIN-** (or "IN-") | black |
| Pololu **VOUT** (5 V) | P4-NANO header pin labelled **5V** | red |
| Pololu **GND** | P4-NANO header pin labelled **GND** | black |

Check with the meter before going on: Pololu VOUT to GND reads **4.9-5.1 V**. If it reads 12 V you wired VIN and VOUT backwards. Power off.

On the bench you can skip the Pololu and just use USB-C for the P4-NANO. You still need 12 V for the PT4115.

## Step 3. Panel side: the 40-pin breakout

1. Open the black latch on the 40-pin breakout's FPC socket (flip up or slide out, depending on the model).
2. Slide the panel's tail in **contacts facing the contacts in the socket**. The Riverdi tail has contacts on one side only; if the picture stays dead later, this is the first thing to flip.
3. Close the latch. Pin 1 of the tail is marked on the panel's drawing; the breakout has "1" printed at one end. Make sure they line up, or every pin below is off by one.

Now wire the breakout's header pins. Pin numbers are the **panel** pin numbers (they match the breakout's printed numbers when pin 1 lines up):

| Breakout pin | Panel signal | Goes to | Wire |
|---|---|---|---|
| 2 **and** 3 | VDD 3.3 V | P4-NANO header **3V3** (use one jumper to pin 2 and a second from pin 2 to pin 3, or a Y) | red |
| 5 | RESET | P4-NANO header **GPIO27** | yellow |
| 6 | STBYB | P4-NANO header **3V3** (same 3.3 V as above) | red |
| 7, 10, 13, 16, 19 | GND | P4-NANO header **GND** (at least two of them; the more the better) | black |
| 31 **and** 32 | LED- | PT4115 **LED-** | black |
| 39 **and** 40 | LED+ | PT4115 **LED+** | red |
| 8 | D0N | 22-pin breakout, DSI **D0-** (Step 4) | pair 1 |
| 9 | D0P | 22-pin breakout, DSI **D0+** | pair 1 |
| 11 | D1N | 22-pin breakout, DSI **D1-** | pair 2 |
| 12 | D1P | 22-pin breakout, DSI **D1+** | pair 2 |
| 17 | DCLKN | 22-pin breakout, DSI **CLK-** | pair 3 |
| 18 | DCLKP | 22-pin breakout, DSI **CLK+** | pair 3 |
| 1, 4, 14, 15, 20, 21, 33-38 | NC / lanes 2-3 | **nothing** | |
| 22-30 | GND / NC / scan direction | leave as the datasheet table says (GND pins to GND, NC open). If the image comes up mirrored later, the U/D and L/R pins here flip it. | |

PT4115 DIM: one jumper from PT4115 **DIM** (may be labelled PWM) to P4-NANO header **GPIO26**.

## Step 4. Video side: the 22-pin breakout on the P4-NANO

The P4-NANO's DSI socket is a 22-pin 0.5 mm FPC. A 22-pin FFC cable goes from the NANO to the 22-pin breakout; then six jumpers go from the breakout to the 40-pin breakout (table in Step 3).

**Which of the 22 pins are which has to be confirmed from the P4-NANO schematic when the board arrives**, because Waveshare's PDF does not have a text table. Schematic: https://files.waveshare.com/wiki/ESP32-P4-NANO/ESP32-P4-NANO-schematic.pdf , find the DSI connector symbol; its nets are `DSI_D0_N`, `DSI_D0_P`, `DSI_D1_N`, `DSI_D1_P`, `DSI_CLK_N`, `DSI_CLK_P`, plus `GPIO7`, `GPIO8`, `GPIO37`, `GPIO38`, 3V3 and GND. Write the pin numbers into the table below and commit it.

Expected layout (the Raspberry Pi 22-pin DSI order that Waveshare's own DSI panels use; **confirm before wiring**):

| 22-pin pin | Expected signal | Confirmed? |
|---|---|---|
| 1 | GND | |
| 2 | DSI D0- | |
| 3 | DSI D0+ | |
| 4 | GND | |
| 5 | DSI D1- | |
| 6 | DSI D1+ | |
| 7 | GND | |
| 8 | DSI CLK- | |
| 9 | DSI CLK+ | |
| 10 | GND | |
| 11-16 | lanes 2/3 on a 4-lane host, unused here | |
| 17-22 | I2C, GPIO37/38, 3V3 | not used by this build |

How to confirm with a meter (board powered **off**): continuity from a 22-pin breakout pin to a GND header pin tells you which pins are ground; the pairs sit between the grounds. That alone fixes pins 1-10 to the pattern above. Which of each pair is + and - cannot be measured; take it from the schematic. If you get a pair swapped the picture will not come up at all, so swapping the two wires of one pair is a legitimate troubleshooting step.

Rules for the six video jumpers:
- Same length, as short as you can (100 mm max on the bench).
- Keep each pair's two wires twisted together or taped side by side.
- Do not run them next to the 12 V wires.

## Step 4b. GPS (speed source)

The P4-NANO has no dedicated GPS header; any two free header GPIOs become a UART. The config uses **GPIO24 = P4 TX, GPIO25 = P4 RX** (change the `gps_tx_pin` / `gps_rx_pin` substitutions if those are taken on the silkscreen).

Four wires. TX goes to RX and RX goes to TX; that is the one everybody gets backwards.

| GPS pin (SparkFun NEO-M9N) | Goes to | Wire |
|---|---|---|
| **3V3** | P4-NANO header **3V3**. **Not 5V: this board is 3.3 V only and 5 V will kill it.** | red |
| GND | P4-NANO header **GND** | black |
| TX (GPS talks) | P4-NANO header **GPIO25** (P4 RX) | green |
| RX (GPS listens) | P4-NANO header **GPIO24** (P4 TX) | white |

(If the Matek M9N-5883 was bought instead: its 5V pin goes to the header **5V**, and its RX/TX pins wire the same way. Its UART is 3.3 V logic too.)

No level shifting needed either way. Keep the antenna (the square ceramic patch) facing the sky with nothing metal on top of it; on the bike that means the top of the enclosure, not under the panel.

### One-time GPS setup (do this on the PC before wiring it to the P4)

Factory default is 1 update per second at 9600 baud, which makes a laggy speedo. We want 10 per second at 115200.

1. Connect the GPS to the USB-TTL adapter with the adapter's switch on **3.3 V**: 3V3-3V3, GND-GND, GPS TX to adapter RX, GPS RX to adapter TX. (If the SparkFun board's USB-C port shows up as a COM port on the PC, use that instead and skip the adapter.)
2. Install u-blox **u-center** (free, Windows). Connect at 9600 (Matek: 38400).
3. View > Messages View > UBX > CFG > RATE: set Measurement Period **100 ms**, click Send.
4. UBX > CFG > PRT: UART1, baud **115200**, Send. Reconnect u-center at 115200.
5. UBX > CFG > CFG: tick "Save current configuration", all devices (BBR + Flash if offered), Send.
6. Power-cycle the module and reconnect at 115200. If it is still at 10 Hz / 115200, done. If it forgot, the module has no flash or battery for settings: uncomment the `on_boot` block in the YAML, which re-sends the same settings every time the dash powers up.

The three UBX command strings the `on_boot` block sends (widely used values, verify against u-center's "Send" hex dump if in doubt):

| Purpose | Bytes |
|---|---|
| 10 Hz (CFG-RATE 100 ms) | `B5 62 06 08 06 00 64 00 01 00 01 00 7A 12` |
| 115200 baud (CFG-PRT UART1) | `B5 62 06 00 14 00 01 00 00 00 D0 08 00 00 00 C2 01 00 07 00 03 00 00 00 00 00 C0 7E` |
| Save (CFG-CFG) | `B5 62 06 09 0D 00 00 00 00 00 FF FF 00 00 00 00 00 00 17 31 BF` |

Test: with the dash running, the log prints satellites, speed and course from the `gps:` component. Outdoors it needs 30-90 s for a first fix; indoors near a window maybe, in a basement never.

## Step 5. Power-on order and first test

1. Meter check, power off: panel pin 2 to any GND must **not** be a short. Panel pin 39 to pin 31 must not be a short.
2. Power the 12 V supply. PT4115 LED output is now live but nothing is drawn yet (it is fine; it is a current source, open circuit is safe).
3. Plug USB-C into the P4-NANO (or turn on the Pololu 5 V).
4. Flash the config **with** the `display:` block. Expect: backlight comes on (Stage 1), screen shows green with a grey box.

| Symptom | Check |
|---|---|
| Backlight off | GPIO26 jumper; DIM floating should mean full on, so if it is still off the PT4115 has no 12 V or LED+/- are swapped |
| Backlight on, screen black, no errors in the log | Reset wire (GPIO27 to pin 5); STBYB tied to 3.3 V; panel tail inserted contacts-down vs contacts-up; THS_ZERO note in hardware.md |
| Log shows DSI errors | A pair swapped, or a pair to the wrong lane; try swapping + and - of one pair, then lanes 0 and 1 |
| Scrambled or rolling picture | `lane_bit_rate` (try 800 or 1000 Mbps), then `pclk_frequency` |
| Picture mirrored | scan-direction pins 22-30 on the panel |
| Panel gets hot | stop; check the PT4115 current (Step 1) |

## Step 6. Bike install (later)

Same connections, but: the two breakouts and jumpers become a carrier PCB, the 12 V comes from a fused ignition-switched feed, the Pololu EN pin follows the ignition, and everything lives in the enclosure with the panel. Do not put jumper wires on a motorcycle.

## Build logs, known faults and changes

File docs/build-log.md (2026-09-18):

# Build log

## 2026-09-18 - research and ordering

- Re-checked whether the Waveshare ESP32-P4-7B was still the right base. Compute: yes. Panel: no, 350 nits.
- Surveyed every ESP32-P4 all-in-one board on sale (Waveshare 7B / 7-8-10.1 HMI / 3.4C / 4C, Guition JC1060P470, Elecrow CrowPanel Advance 7, M5Stack Tab5). All 350-450 nits, all 0-60 C. None sunlight-readable.
- Found Riverdi RVT70HSMNWC00-B: 850 nits optical-bonded touch, -20 to 70 C, EK79007 controller, 2-lane capable per its own init code. $113.52 direct, $116.07 DigiKey (10 in stock).
- Confirmed ESPHome `mipi_dsi` has `model: CUSTOM` with `init_sequence`, `lanes: 2`, and a `WAVESHARE-P4-NANO-10.1` preset exists for the board.
- Confirmed the Riverdi backlight needs an external constant-current driver (9.6 V / 270 mA). Chose PT4115 modules (12 V in) and a Pololu D36V28F5 for 5 V.
- Amazon cart built (P4-NANO, 40P + 22P breakouts, PT4115 x3, Pololu). $71.15. Panel to be ordered from DigiKey.
- Rejected: Pi/CM5 (boot time), STM32H7 (no BLE), Amazon "1000 nit" HDMI kits (no HDMI on P4).
- Open items: which of GPIO37/38 on the P4-NANO DSI connector is LCD reset; PT4115 sense resistor value on the modules that arrive; 22-pin FFC cable orientation.
- Caught later the same day: the GPS (speed source) had been left out of this repo. Added to the BOM (SparkFun NEO-M9N chip-antenna breakout, $74.95 Prime, 3.3 V, backup battery; Matek M9N-5883 as the fallback; plus a USB-TTL adapter for the one-time 10 Hz / 115200 setup), wiring.md Step 4b, and `uart:` + `gps:` blocks in the YAML on GPIO24/25. Not ordered yet.
- Local repo moved to `C:\Users\anon\Nextcloud\server\bike-dash-build` (Nextcloud-synced).
- All core parts (rows 1-8 in bom.md) ordered 2026-09-18. Bench extras (22-pin FFC cable, jumpers, 12 V supply) still to buy when the boxes arrive.
- Enclosure mockup (gaming PC, OpenSCAD 2021.01): four parts (bezel, retainer plate, shell, GPS cap) in `enclosure/`, STLs and previews exported. P4-NANO outline (50 x 50, holes 45.10 x 45.09) and SparkFun M9N board drawing (40.64 x 33.02, holes 35.56 x 27.94) fetched from the vendor drawings. The Riverdi -B touch datasheet 404s on every revision tried, so the glass outline is from the listing and tagged VERIFY. PT4115 and breakout boards are on adhesive pads until measured.

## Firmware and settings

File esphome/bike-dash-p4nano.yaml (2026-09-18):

# bike-dash on Waveshare ESP32-P4-NANO + Riverdi RVT70HSMNWC00-B (7" 1024x600, 850 nit)
# Stage 0/1 bring-up config. Validate with `esphome config` first.
# Pins follow docs/wiring.md: panel RESET on GPIO27, PT4115 DIM on GPIO26 (P4-NANO BSP defaults).

substitutions:
  name: bike-dash
  lcd_reset_pin: GPIO27
  backlight_pwm_pin: GPIO26
  gps_tx_pin: GPIO24   # P4 TX -> GPS RX. Any free header GPIO; check the silkscreen
  gps_rx_pin: GPIO25   # P4 RX <- GPS TX

esphome:
  name: ${name}

esp32:
  variant: esp32p4
  flash_size: 16MB
  cpu_frequency: 360MHz
  framework:
    type: esp-idf
    # sdkconfig_options:
    #   CONFIG_ESP_MAIN_TASK_STACK_SIZE: "16384"

psram:
  mode: hex
  speed: 200MHz

logger:
  hardware_uart: UART0
  level: DEBUG

# Onboard ESP32-C6 (Wi-Fi 6 / BLE) over SDIO. Values from the ESPHome device page for the P4-NANO.
esp32_hosted:
  variant: ESP32C6
  active_high: true
  reset_pin: GPIO54
  cmd_pin: GPIO19
  clk_pin: GPIO18
  d0_pin: GPIO14
  d1_pin: GPIO15
  d2_pin: GPIO16
  d3_pin: GPIO17

api:
ota:
  platform: esphome

wifi:
  ssid: !secret wifi_ssid
  password: !secret wifi_password

i2c:
  sda: GPIO7
  scl: GPIO8
  frequency: 400kHz

# GPS: u-blox M8/M10 on a UART. Module must be set to 10 Hz / 115200 (docs/wiring.md Step 4b).
uart:
  - id: gps_uart
    tx_pin: ${gps_tx_pin}
    rx_pin: ${gps_rx_pin}
    baud_rate: 115200
    rx_buffer_size: 2048

gps:
  uart_id: gps_uart
  latitude:
    name: GPS Latitude
  longitude:
    name: GPS Longitude
  altitude:
    name: GPS Altitude
  satellites:
    name: GPS Satellites
  course:
    name: GPS Course
  speed:
    name: GPS Speed
    id: gps_speed_kmh
    # ESPHome reports km/h; the dash wants mph
    on_value:
      then:
        - sensor.template.publish:
            id: speed_mph
            state: !lambda 'return x * 0.621371;'

sensor:
  - platform: template
    id: speed_mph
    name: Speed
    unit_of_measurement: mph
    accuracy_decimals: 0

time:
  - platform: gps
    id: gps_time

# If the GPS module forgets its 10 Hz / 115200 setting on power loss (no flash / no battery),
# move this on_boot block under the existing `esphome:` key at the top so the dash re-sends it
# at every boot. The module boots at 9600 in that case, so the first two writes go out at 9600,
# then the UART is switched to 115200.
#   on_boot:
#     priority: -100
#     then:
#       - lambda: |-
#           id(gps_uart).set_baud_rate(9600); id(gps_uart).load_settings();
#       - uart.write: {id: gps_uart, data: [0xB5,0x62,0x06,0x08,0x06,0x00,0x64,0x00,0x01,0x00,0x01,0x00,0x7A,0x12]}
#       - uart.write: {id: gps_uart, data: [0xB5,0x62,0x06,0x00,0x14,0x00,0x01,0x00,0x00,0x00,0xD0,0x08,0x00,0x00,0x00,0xC2,0x01,0x00,0x07,0x00,0x03,0x00,0x00,0x00,0x00,0x00,0xC0,0x7E]}
#       - delay: 200ms
#       - lambda: |-
#           id(gps_uart).set_baud_rate(115200); id(gps_uart).load_settings();

# Backlight: LEDC PWM into the PT4115 DIM pin. About 5 kHz so it is not visible.
output:
  - platform: ledc
    id: backlight_pwm
    pin: ${backlight_pwm_pin}
    frequency: 5000Hz

light:
  - platform: monochromatic
    id: backlight
    name: Backlight
    output: backlight_pwm
    restore_mode: ALWAYS_ON

display:
  - platform: mipi_dsi
    id: main_display
    model: CUSTOM
    dimensions:
      width: 1024
      height: 600
    lanes: 2
    lane_bit_rate: 900Mbps        # try 800-1000 if scrambled
    pclk_frequency: 51.2MHz       # datasheet typ; 44.9-63 MHz allowed
    hsync_pulse_width: 70
    hsync_back_porch: 160
    hsync_front_porch: 160
    vsync_pulse_width: 10
    vsync_back_porch: 23
    vsync_front_porch: 12
    reset_pin: ${lcd_reset_pin}
    # Riverdi datasheet p.16, verbatim. 0xB2 0x50 = 2-lane.
    init_sequence:
      - [0x01]
      - delay 120ms
      - [0xB2, 0x50]
      - [0x80, 0x4B]
      - [0x81, 0xFF]
      - [0x82, 0x1A]
      - [0x83, 0x88]
      - [0x84, 0x8F]
      - [0x85, 0x35]
      - [0x86, 0xB0]
      - [0x11]
      - delay 120ms
      - [0x29]
      - delay 20ms
    auto_clear_enabled: false
    update_interval: never
    # Stage 1 test: fill the screen. Replace with the LVGL block from bike-dash at Stage 3.
    lambda: |-
      it.fill(Color(0, 80, 0));
      it.filled_rectangle(100, 100, 824, 400, Color(200, 200, 200));

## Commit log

2026-09-18 Initial build docs: decision, BOM, wiring guide, hardware notes, ESPHome bring-up config
    Claude-Session: https://claude.ai/code/session_01PSavJXLduRMF9NHnqv8jfb
2026-09-18 Add GPS speed source: SparkFun NEO-M9N in BOM, wiring step 4b, uart+gps blocks in config
    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
2026-09-18 BOM: all core parts ordered 2026-09-18
    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
2026-09-18 BOM: drop stale GPS row from on-bike list
    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
2026-09-18 Add colour-coded wiring diagram (SVG) and embed it in the wiring guide
    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
2026-09-18 README: embed the wiring diagram
    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
2026-09-18 BOM: XIAO ESP32-C6 as the second-radio contingency
    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
2026-09-18 Hardware: antenna rules for the bike install
    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
2026-09-18 Enclosure: OpenSCAD model, STLs and previews for the four printed parts
    Bezel (M3 inserts, glass + TFT pockets), retainer plate, rear shell with
    P4-NANO standoffs, PG7 gland, AMPS bosses, and a GPS cap on the top edge
    for the SparkFun NEO-M9N. Dimensions from the vendor drawings; unverified
    ones tagged VERIFY in the .scad and listed in enclosure/README.md.
    Claude-Session: https://claude.ai/code/session_011wPTfikiL8dYkQT2M3fSgD
    [bezel.stl, bike-dash-enclosure.scad, gpscap.stl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]
